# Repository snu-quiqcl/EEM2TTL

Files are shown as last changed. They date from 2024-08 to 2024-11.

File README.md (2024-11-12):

# EEM2TTL
<p align="center">
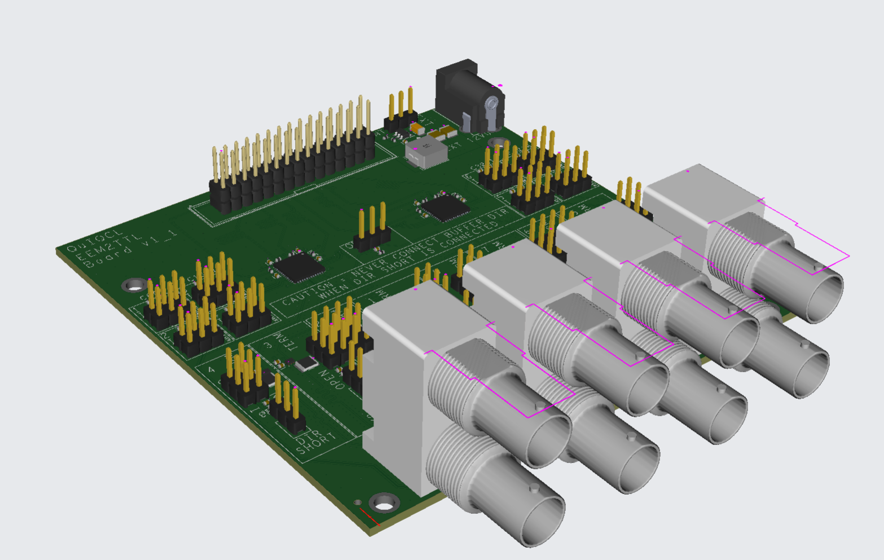
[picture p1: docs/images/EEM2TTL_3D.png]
    
</p>

## Overview
<p align="center">
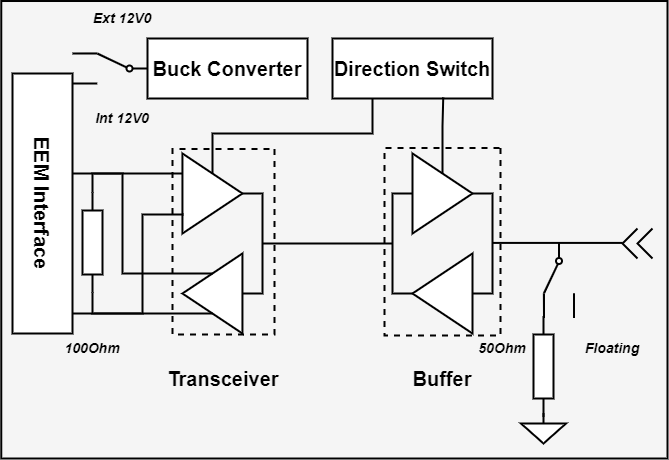
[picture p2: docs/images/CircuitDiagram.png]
    
</p>

The EEM2TTL PCB board converts electrical signals between the LVDS interface and 3.3V TTL signals. It allows for selectable signal direction and optional 50-ohm termination. Power can be supplied either through the EEM interface or an external 12V power pin.

## Board Configuration
<p align="center">
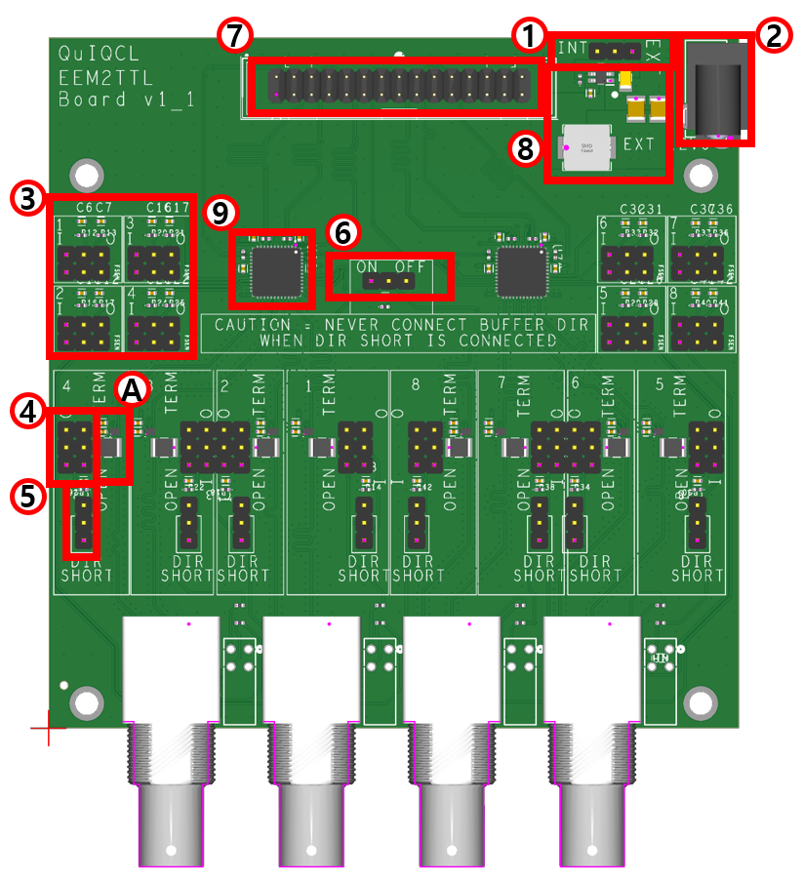
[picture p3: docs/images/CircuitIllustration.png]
    
</p>

<p align="center">
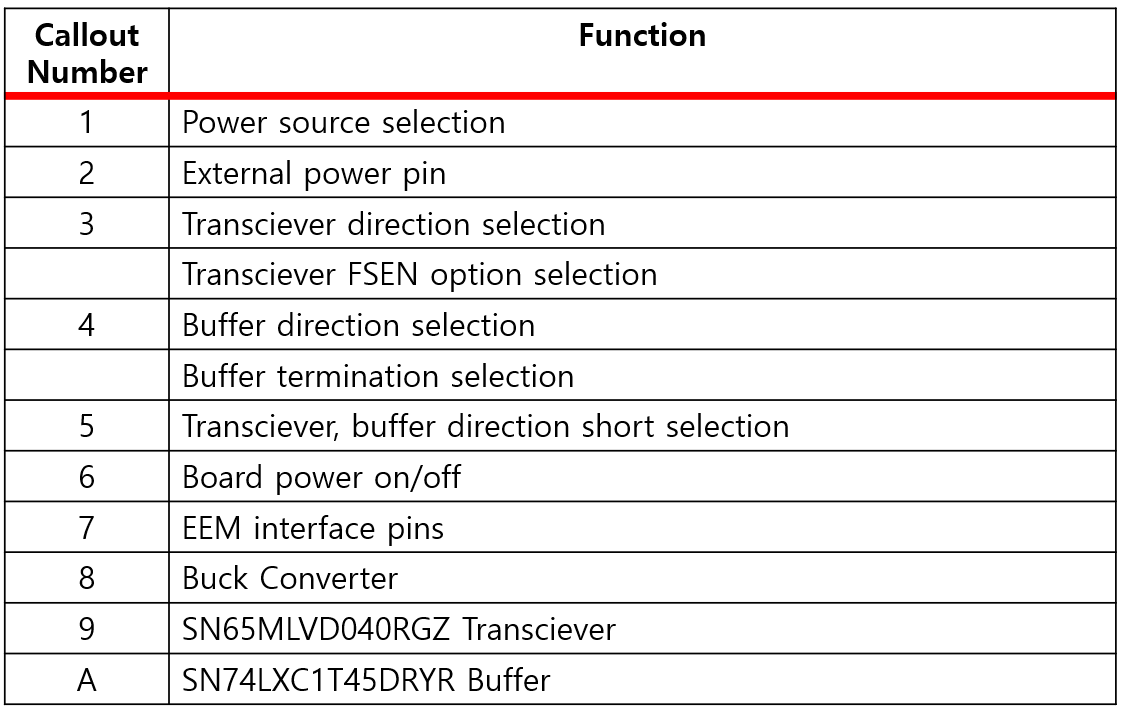
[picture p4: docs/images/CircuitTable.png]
    
</p>

## Jumper Configuration
### 1:Power Source Selection
When the power source selection jumper is connected to the `INT` pin, the 12V power is supplied from the EEM interface. Conversely, if connected to the `EXT` pin, the 12V power is supplied from an external power source pin.

### 3:Transciever Option Selection
Each transceiver has four I/Os, and the direction of each I/O can be selected individually. Each I/O option is configured with a dedicated jumper, marked with an index number on the board. The upper jumper, labeled `I` and `O`, controls the transceiver's direction. When connected to `I`, it receives signals from TTL to EEM, and when set to `O`, it transmits signals from EEM to TTL. The lower jumper selects the FSEN option for M-LVDS, which stabilizes output even when the input LVDS signal is close to the threshold level and oscillating slightly.

### 4:Buffer Option Selection
A buffer chip is positioned directly behind the BNC port to increase output signal current. The direction of each signal can be selected by adjusting jumpers. Connecting the jumper to `I` routes the input signal from the BNC to the transceiver, while connecting it to `O` sends the signal from the transceiver to the BNC port. The `OPEN` and `TERM` jumper is used to control the BNC’s 50-ohm termination; connecting it to `OPEN` leaves the BNC open, while connecting it to `TERM` provides a 50-ohm termination on the board. This setup helps reduce signal reflection when receiving long-distance input signals.

### 5:Direction Short Option Selection
The transceiver and buffer directions must be matched. Each direction can be selected individually on the board, mainly for debugging purposes, but this feature is typically not used. Connecting the jumper to `DIR SHORT` synchronizes the transceiver and buffer directions. When using this setting, never connect both the transceiver and buffer direction jumpers simultaneously, as this could short 3.3V and 0V. It is recommended to leave the I/O direction jumper on the buffer open and control the direction using only the transceiver direction jumper.

### 6:On/Off Switch
When jumper is connected to `ON`, board is turned on, and vice versa.

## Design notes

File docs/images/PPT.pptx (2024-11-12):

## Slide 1

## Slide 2

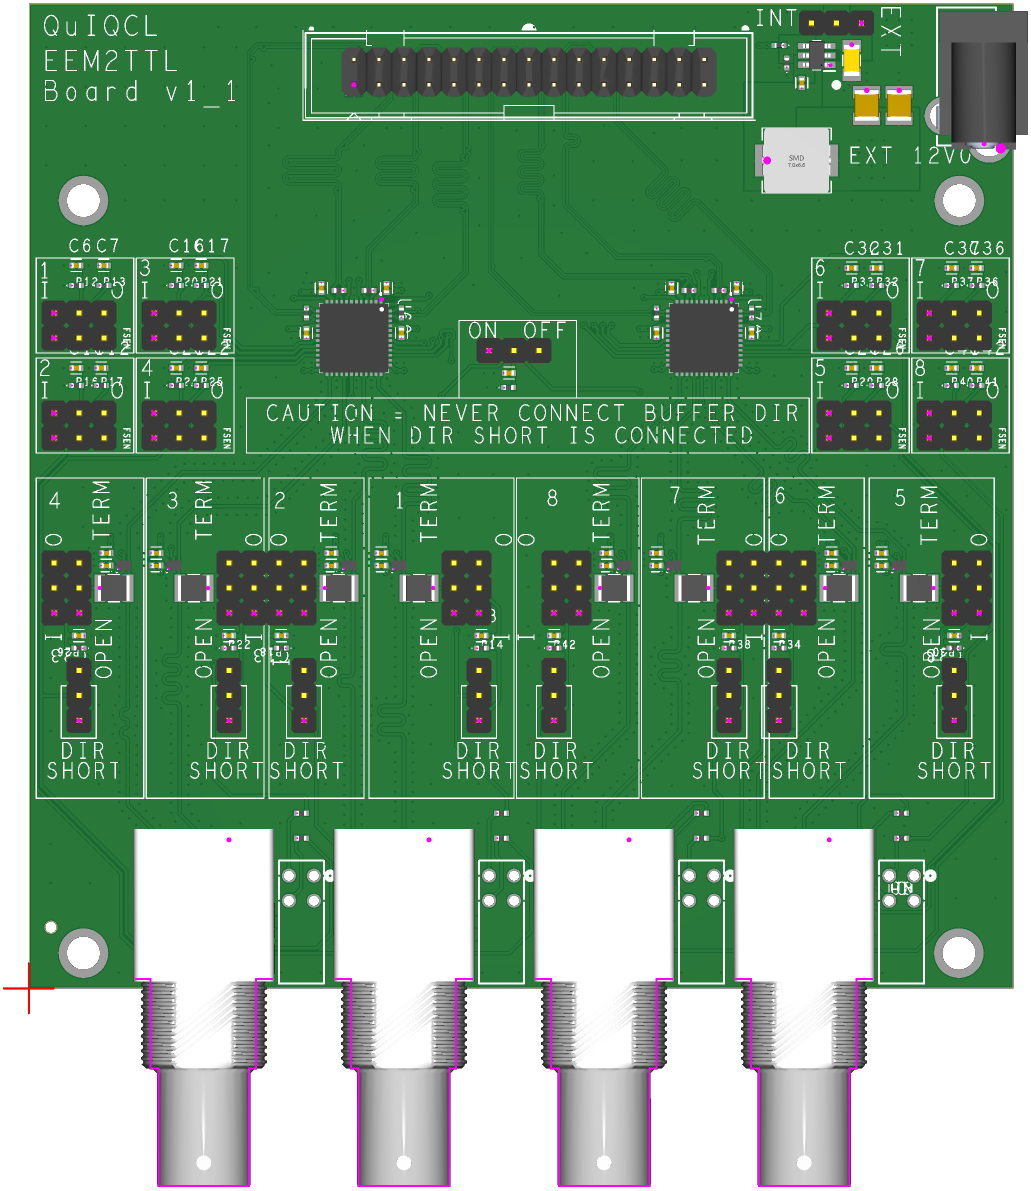
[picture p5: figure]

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
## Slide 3

Callout Number | Function
1 | Power source selection
2 | External power pin
3 | Transciever direction selection
| Transciever FSEN option selection
4 | Buffer direction selection
| Buffer termination selection
5 | Transciever, buffer direction short selection
6 | Board power on/off
7 | EEM interface pins
8 | Buck Converter
9 | SN65MLVD040RGZ Transciever
A | SN74LXC1T45DRYR Buffer

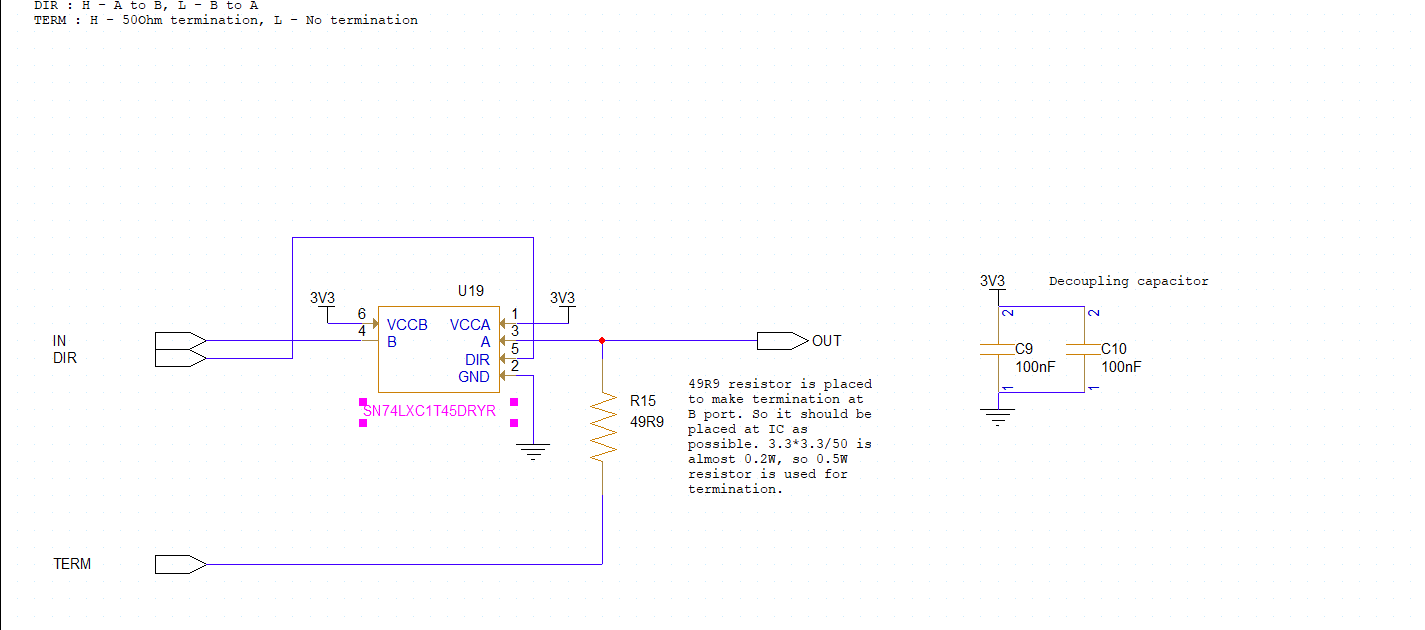
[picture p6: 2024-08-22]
EEM2TTLv1_1/EEM2TTL.png

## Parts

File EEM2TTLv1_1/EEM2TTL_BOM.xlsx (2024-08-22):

Comment | Designator | Footprint
C1005X5R1E104KT000E | C1,C2,C6,C7,C8,C9,C10,C11,C12,C13,C14,C15,C16,C17,C18,C19,C20,C21,C22,C23,C24,C25,C26,C27,C28,C29,C30,C31,C32,C33,C34,C35,C36,C37,C38,C39,C40,C41,C42,C43,C44,C45,C46,C47,C48,C49,C50,C51,C52,C53 | C1005X5R1E104KT000E
CL31A106KBHNNNE | C3 | CL31A106KBHNNNE
TMK325BJ226MM-T | C4,C5 | TMK325BJ226MM-T
DC-005-20A | J1 | DC-005-20A
MECHHOLE | M1,M2,M3,M4 | MECHHOLE
AP62201WU-7 | PS1 | AP62201WU-7
RC-02W300JT | R1,R2,R3,R4,R5,R6,R7,R8 | RC-02W300JT
ERJ2RKF1002X | R9,R11,R12,R13,R14,R16,R17,R18,R20,R21,R22,R24,R25,R26,R28,R29,R30,R32,R33,R34,R36,R37,R38,R40,R41,R42 | ERJ2RKF1002X
CR0402F31K6Q10Z | R10 | CR0402F31K6Q10Z
AC1210FR-0749R9L | R15,R19,R23,R27,R31,R35,R39,R43 | AC1210FR-0749R9L
0402WGF1000TCE | R44,R45,R46,R47,R48,R49,R50,R51 | 0402WGF1000TCE
PZ2.54-2*15 | U1 | PZ2.54-2*15
WP934EB/2GD | U2,U3,U4,U5 | WP934EB/2GD
DOSIN-801-0093 | U6,U7,U8,U10 | DOSIN-801-0093
2.54-1*3P | U9,U11,U14,U15,U16,U17,U18,U21,U22,U23,U24,U25,U28,U29,U30,U31,U32,U35,U36,U37,U38,U39,U42,U43,U44,U45,U46,U49,U50,U51,U52,U53,U56,U57,U58,U59,U60,U63,U64,U65,U66,U67 | 2.54-1*3P
MWSA0603S-3R3MT | U12 | MWSA0603S-3R3MT
SN74LXC1T45DRYR | U19,U26,U33,U40,U47,U54,U61,U68 | SN74LXC1T45DRYR
SN65MLVD040RGZR | U69,U70 | SN65MLVD040RGZR

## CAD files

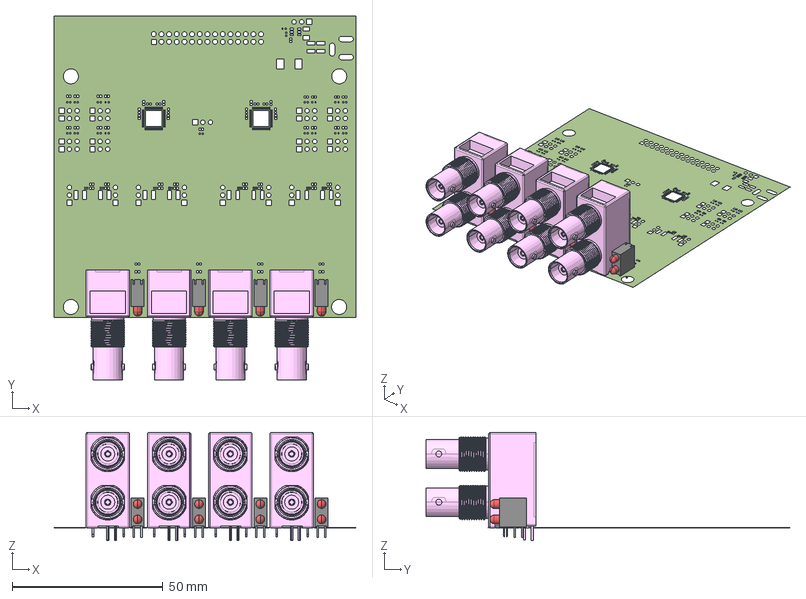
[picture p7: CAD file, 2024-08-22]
EEM2TTLv1_1/Board.stp
100.0 x 120.6 x 35.8 mm
SOLDERMASK_TOP
DOSIN-801-0093 x 4
IC4_WP934EB2GD_KNB x 4

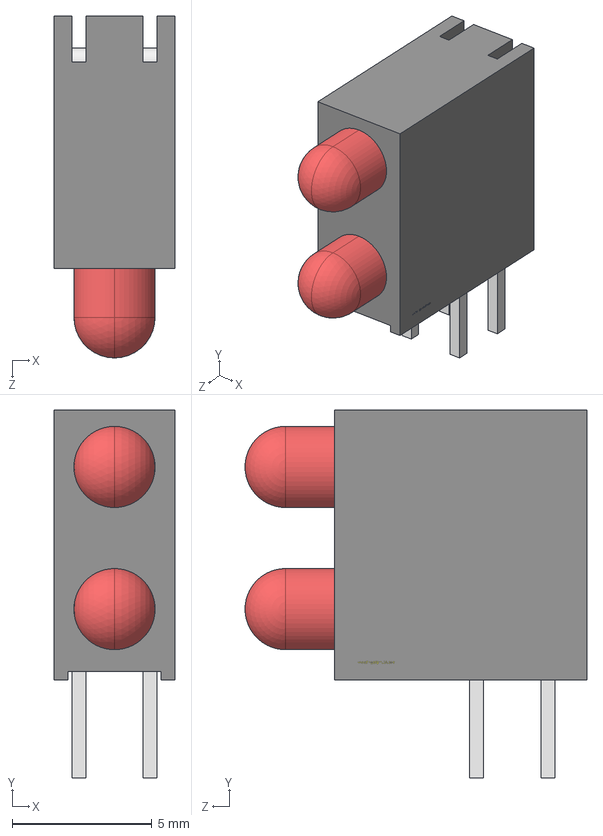
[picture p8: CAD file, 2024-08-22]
EEM2TTLv1_1/STEP/WP934EB.STEP
4.32 x 13.2 x 12.2 mm

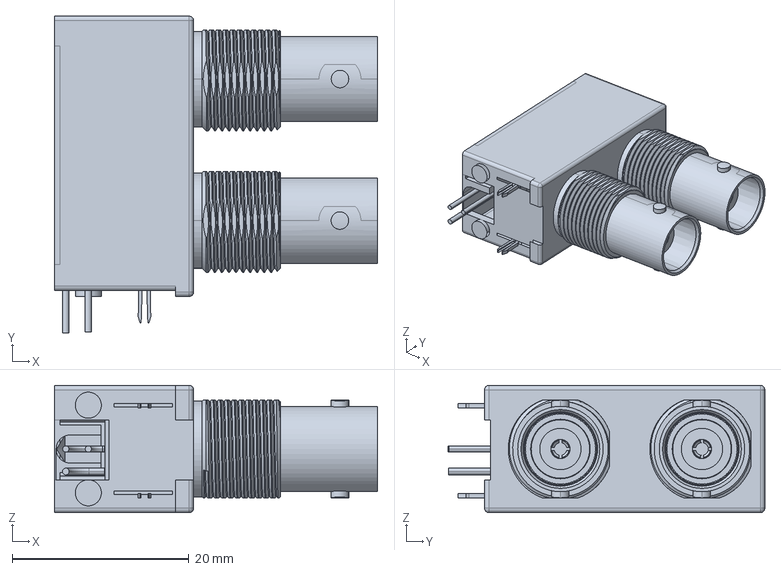
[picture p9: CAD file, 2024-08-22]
EEM2TTLv1_1/STEP/DOSIN-801-0093.stp
36.5 x 35.8 x 14.4 mm

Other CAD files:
EEM2TTLv1_1/Board/Board.iam
EEM2TTLv1_1/Board/DOSIN-801-0093.ipt
EEM2TTLv1_1/Board/DOSIN-801-0093_1.ipt
EEM2TTLv1_1/Board/DOSIN-801-0093_2.ipt
EEM2TTLv1_1/Board/DOSIN-801-0093_3.ipt
EEM2TTLv1_1/Board/IC4_WP934EB2GD_KNB.ipt
EEM2TTLv1_1/Board/IC4_WP934EB2GD_KNB_1.ipt
EEM2TTLv1_1/Board/IC4_WP934EB2GD_KNB_2.ipt
EEM2TTLv1_1/Board/IC4_WP934EB2GD_KNB_3.ipt
EEM2TTLv1_1/Board/OldVersions/Board.0001.iam
EEM2TTLv1_1/Board/SOLDERMASK_TOP.ipt
EEM2TTLv1_1/Board/Shapes.iam
EEM2TTLv1_1/Board/Symbols.iam

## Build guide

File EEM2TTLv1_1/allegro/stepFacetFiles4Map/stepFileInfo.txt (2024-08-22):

#STEP_FILE ! FILE_SIZE ! MOD_TIME

DOSIN-801-0093.stp ! 1706401 ! 1722294184
WP934EB.STEP ! 1988769 ! 1722322516

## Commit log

2024-07-27 Initial Push
    [EEM2TTL.DSN, EEM2TTL_BOM.xlsx, art_param.txt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]
2024-08-22 Wrong port is corrected
    [Board.0001.iam, Board.iam, Board.stp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]
